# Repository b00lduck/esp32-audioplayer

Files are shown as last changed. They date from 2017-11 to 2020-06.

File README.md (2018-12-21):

# esp32-audioplayer
ESP32 based MP3 audio player with RFID control and case made from laser cutted plywood

!!! WORK IN PROGRESS !!!
!!! not functional yet !!!

## Used electronic hardware components:
* ESP32 NodeMCU module
* RFID-RC522 module (i.e. https://www.ebay.de/itm/172603664748)
* VS1053B module with SD-slot (i.e. http://www.ebay.de/itm/272761135002)
* Mifare classic 13.56MHz RFID cards (clones will do the job too, i.e. http://www.ebay.de/itm/122525501095)
* Adafruit PowerBoost 500 Charger module
* 3.7V LiPo battery 
* Class-D amplifier module
* SD-Card (i.e. 4GB)
* two Visaton FR7 (4 ohms) speakers
* Custom main board (see kicad folder for layout)
* Custom panel board (see kicad folder for layout)
* 1x 220uF 35V
* 1x 1uF 63V
* 4x 100nF 
* 2x 47nF
* 1x resistor ladder 4x 4.7k
* 1x 10R 
* 1x 10kR
* 1x 22kR
* 4x WSL10 (2x5 header 2.54mm with notch)
* 2x 2-pin header 2.54mm
* 4x 4-pin header 2.54mm
* some wire for airwires
* some insulated wire 1mm², red and black (for internal connections)
* 1x USB 2 Micro-B connector
* 1x power switch
* 1x USB 2 micro cable (for internal connection)
* optional: MEMS gyroscope module
* optional: 0.96 inch I2C OLED display

## Wood parts:
* 6 sheets, one for every side of the case
* 2 distance rings for the speakers

## Metal parts:
* 2x 100x75x0.8mm aluminium sheet

## 3D-Printed parts:
* 8x inner edge reinforcements
* 4x M3x3 standoff
* 8x M3*8 standoff (for main board)
* 4x M3x11 standoff (for MP3 board)
* 2x M3x6 standoff (for panel board)
* 2x M3x4 standoff (for panel board)
* 1x USB receptacle holder
* 1x SD-Card slot box
* 1x SD-Card slot cover

## Screws
* 4x M3x25 DIN 7991/ISO 10642 (countersunk allen bolt)
* 32x M3 DIN 934/ISO 4042 (nut)
* 8x M3 DIN 125/ISO 7089 (washer)
* 8x M3x20 DIN 912/ISO 4762 (cylinder head allen bolt)
* 2x M2x10 DIN 912/ISO 4762 (cylinder head allen bolt) for amp
* 2x M2 DIN 934/ISO 4042 (nut)
* 2x M2 DIN 125/ISO 7089 (washer)
* 8x M3x?? DIN 7991/ISO 10642 (countersunk allen bolt) for speakers
* 24x M3x15 DIN 7991/ISO 10642 (countersunk allen bolt) for inner corners

## Used software:
* VSCode with PlatformioIDE

## Used Arduino Libraries:
* SdFat 1.0.7
* MFRC522 1.3.6

## Port mapping
see src/config.h

## 3D printing
I used black 1.75 PETG filament for all parts.
Layer height was 0.15mm at a printign speed of 30mm/s.

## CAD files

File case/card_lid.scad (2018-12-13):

$fn  = 50;

width = 40;
height = 15;

// lid
lidThickness = 2.8;
pinLength = 4;
pinWidth = 5;
pinThickness = lidThickness / 2;
boxToLidSpacing = 1;
pinSpacing = 0.5;
lidReinforcementDepth = 2;

screwHoleHeadDiameter = 6;
screwHoleHeadDepth = 2;
screwHoleDiameter = 3.2;
screwHoleDistance = 6;

boxOverlap = 10;
boxThickness = 2;
boxDepth = 10;
boxKragen = 1.6;
boxFloorThickness = 3;

screwPoleDiameter = 8;

woodWidth = 4;

clipThickness = 0.6;
clipWidth = 4;
clipHeight = 5;
clipNoseHeight = 2;
clipNoseThickness = 1;
clipRadius = 1;

clipToWoodThruSpacing = 0.25;

lid();
//box();

module solidBox() {
    
    // kragen
    translate([0,0,-boxThickness/2]) cube([width + boxOverlap, height + boxOverlap, boxThickness], true);
 
    // durchführung
    translate([0, 0, (woodWidth)/2 - clipToWoodThruSpacing/2]) cube([width + boxThickness * 2, height + boxThickness * 2, woodWidth - clipToWoodThruSpacing], true);
 
    // rest
    translate([0, 0, (boxDepth-woodWidth-clipToWoodThruSpacing)/2 + woodWidth]) cube([width + (boxThickness - boxKragen) * 2, height + (boxThickness - boxKragen) * 2, boxDepth - woodWidth + clipToWoodThruSpacing], true);
    //snapClips();
}

module snapClips() {

    for(i = [-width/4,width/4])
    translate([i,0,0]) {
        translate([0, height/2 + boxThickness - boxKragen - clipThickness, woodWidth]) snapClip();
        rotate([180,180,0]) translate([0, height/2 + boxThickness - boxKragen - clipThickness, woodWidth]) snapClip();
    }

    translate([width/2 + boxThickness - boxKragen - clipThickness, 0, woodWidth]) rotate([0,0,-90]) snapClip();
    translate([-(width/2 + boxThickness - boxKragen - clipThickness), 0, woodWidth]) rotate([0,0,90]) snapClip();
}


module hollowBox() {      
   difference() { 
      solidBox();
             
      // oberer teil
      translate([-width/2,-height/2,-boxThickness]) cube([width, height, lidThickness]);    
      
      // unterer teil
      translate([0,0,boxDepth/2 - (boxFloorThickness-boxThickness)]) cube([width - boxKragen * 2, height - boxKragen * 2, boxDepth - boxThickness], true);    
       
       // pin slots
       pins();  
        
       // sd card slot
       translate([-4,0,boxDepth-boxFloorThickness/2]) cube([25,3,boxFloorThickness], true); 
   }   
   
}

module hollowBoxWithScrewPost() {
    difference() {
        hollowBox();
        translate([width/2-screwHoleDistance,0, lidThickness - boxThickness]) {
            cylinder(boxDepth-lidThickness, 2, 2);           
        }
    }

    translate([width/2-screwHoleDistance,0, lidThickness - boxThickness]) {
        difference() {
            screwPost();
            cylinder(boxDepth-lidThickness, 2, 2);           
        }    
   }
}

module box() {
    
    difference() {
        hollowBoxWithScrewPost();
        
        // M3 nut
        translate([width/2-screwHoleDistance,0,boxDepth]) 
        linear_extrude(height = 4, center = true) polygon([
            [3.17543,0],
            [1.58771,-2.75],
            [-1.58771,-2.75],
            [-3.17543,0],
            [-1.58771,2.75],
            [1.58771,2.75]
        ]);
        
        // notch for opening lid
        translate([width/2,-5,-3.4]) rotate([60,0,90]) cube([10,3.6,2]);      
    }    
}


module snapClip() {
       
    clipInnerRadius = clipRadius - clipThickness;
    
    translate([-clipWidth / 2, 0, 0]) {
    
        cube([clipWidth, clipThickness, clipHeight]);
        translate([0,clipRadius,clipHeight]) rotate([0,90,0]) 
        difference() {
            cylinder(clipWidth, clipRadius, clipRadius);
            cylinder(clipWidth, clipInnerRadius, clipInnerRadius);
            translate([0, -clipInnerRadius,0]) cube([clipInnerRadius * 3,clipInnerRadius * 2, clipWidth]);
        }
        translate([0,clipRadius*2 - clipThickness,0]) cube([clipWidth, clipThickness, clipHeight]);
        
        translate([clipWidth,clipRadius*2,0]) rotate([0,-90,0]) linear_extrude(height = clipWidth) polygon([
            [0, 0],
            [0, clipNoseThickness],
            [clipNoseHeight, 0]        
        ]);    
    }
}

module screwPost() {
    translate([0,0,lidReinforcementDepth]) cylinder(boxDepth-lidThickness-lidReinforcementDepth, screwPoleDiameter/2, screwPoleDiameter/2);
    translate([0,0,6.2]) cube([9,13,0], true);
}

module lidWithReinforcement() {
    translate([0,0,0]) {
        cube([width - boxToLidSpacing, height - boxToLidSpacing, lidThickness]);
        translate([screwHoleDistance, height/2, lidThickness]) cylinder(lidReinforcementDepth, screwPoleDiameter/2, screwPoleDiameter/2);
    }
}

module lid() {
    rotate([0,0,180]) translate([-width/2+boxToLidSpacing/2,-height/2+boxToLidSpacing/2,-boxThickness]) {
        difference() {
            lidWithReinforcement();
            translate([screwHoleDistance, height/2, 0]) cylinder(lidThickness + lidReinforcementDepth, screwHoleDiameter/2, screwHoleDiameter/2);
            translate([screwHoleDistance, height/2, 0]) cylinder(screwHoleHeadDepth, screwHoleHeadDiameter/2, screwHoleHeadDiameter/2);
       }
    }
    translate([0,0,0]) pins(pinSpacing);
 }
 
module pins(spacing = 0) {
    for(i = [-1,1]) 
        translate([(-pinLength-width)/2 , - pinWidth/2 + i*height/4, lidThickness/2 - boxThickness + spacing]) {
            cube([pinLength, pinWidth - spacing, pinThickness - spacing]);
        }
}

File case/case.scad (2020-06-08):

include <speakers.scad>;

$fn = 150;

width = 185;
depth = 110;
height = 110;

// 3.6 mm Pappel settings
//material = 3.6;
//kerf = 0.07;
//kerfExtraToothLen = 0.2;
//edgeHoleDistance = 11.6; // 11mm + ?
//edgeHoleRadius = 2

// 3 mm Plexi settings
material = 3;
kerf = 0.04;
kerfExtraToothLen = 0.2;
edgeHoleDistance = 11.8; // 11mm + ?
edgeHoleRadius = 1.6;

// 4 mm Birke settings
//material = 4;
//kerf = 0.07;
//kerfExtraToothLen = 0.2;



buttonDiameter = 24; 
//outerButtonDiameter = 34;
buttonSpread = 36;
buttonSpacing = 25;
buttonFoo = 0;

speakerHoleDistance = 60.5;
speakerDiameter = 70;
speakerSluts = 2.5;

fingersA = 9;
fingersB = 4;



//dimensions();

/*
    Material dimensions needed:
                                       
    1   top/bottom      240mm x 200mm   
    2   front/back      240mm x 200mm
    3   left/right      240mm x 120mm
    4   speaker ring    210mm x 110mm


    Cost for two cases without room for error:

    Rauchglas braun getoent     5mm     30€ (without rings)
    Rauchglas braun getoent     3mm     27€
    hellblau 5C18               3mm     30€
    Transparent                 5mm     21€ (without rings)
    Transparent                 3mm     21€
    Transparent kratzfest       3mm     29€
    grau 7C83                   3mm     31€ 
       
    https://www.plattenzuschnitt24.de/Acrylglas-Zuschnitt/Acrylglas-getoent/
    https://acrylglasplattenshop.de/acrylglas-getoent/       
    https://expresszuschnitt.de/3mm-PLEXIGLAS-hellgrau-GS-nach-Mass 
*/

color([1,0,0]) {
    //sheet1(); // front/bottom
    //sheet2(); // top/back
    sheet3(); // left/right
    //sheet4(); // speaker ring
    //kerftest();
}

module kerftest() {   
    sq = 40;    
    translate([0,-21,0]) {
        reducedSquare(sq, sq);
        fingersA(40, 40, 3, 0.5);
        fingersB(40, 40, 3, 0, true);
    }

    translate([0,21,0]) {
        reducedSquare(sq, sq);
        fingersA(40, 40, 3, 0);
        fingersB(40, 40, 3, 0);
    }
}

module dimensions() {
    difference() {
        square([211,111],true);
        square([210,110],true);
    }
}

module sheet1() {
    // front
    translate([60,0]) rotate([0,0,90]) faceA(width, depth);

    // bottom
    translate([-60,0,0]) rotate([0,0,90]) difference() {
        faceB(width, depth);
        translate([width/2 - 45.8,height/2 - 32,0]) circle(1.8);
        translate([-width/2 + 45.8,height/2 - 32,0]) circle(1.8);
        translate([width/2 - 45.8,height/2 - 98.8,0]) circle(1.8);
        translate([-width/2 + 45.8,height/2 - 98.8,0]) circle(1.8);
    }
}

module sheet2() {
    
    translate([-60,0,0]) rotate([0,0,90]) difference() {
        faceA(width, depth);
        translate([-10, 6]) sdCut();
        translate([55,14]) usbCut();
        translate([-65,17]) powerCut();
        translate([width/2 - 25.5, -height/2 + 27]) phoneCut();
        translate([width/2 - 26.5, -height/2 + 55]) ledsCut();
    }

    
    /*
    translate([60,0,0]) rotate([0,0,90]) difference() {
        faceB(width, depth);
        translate([-buttonSpread,-buttonSpacing+buttonFoo]) circle(buttonDiameter/2);
        translate([0,-buttonSpacing]) circle(buttonDiameter/2);
        translate([buttonSpread,-buttonSpacing+buttonFoo]) circle(buttonDiameter/2);
        rfid();
    }
    */
    
}

module rfid() {    
    distA = 34 / 2;
    distB = 25 / 2;   
    distC = 37 / 2;    
    translate([0,20,0]) {
        // two holes are enough and so the asymmetry of the board will be hidden
        translate([distC,distA,0]) circle(edgeHoleRadius);
        //translate([-distC,distB,0]) circle(edgeHoleRadius);
        //translate([distC, -distA,0]) circle(edgeHoleRadius);
        translate([-distC,-distB,0]) circle(edgeHoleRadius);
    }
}

module phoneCut() {
    circle(5.5);
}

module ledsCut() {
    translate([-5,0]) circle(2.1);
    translate([5,0]) circle(2.1);
}

module sdCut() {
    square([43.7 - kerf * 2, 18.7 - kerf * 2]);
}

module usbCut() {
    square([22 - kerf * 2, 11 - kerf * 2]);
}

module powerCut() {
    square([13,19], true);
}

module sheet3() {    
    translate([-60,0,0]) difference() {
        faceC(height, depth);
        rotate([0,0,90]) speakerCuts2(speakerHoleDistance, 4, speakerDiameter, 1.7);
    }
    translate([60,0,0]) difference() {
        faceC(height, depth);
        rotate([0,0,90]) speakerCuts2(speakerHoleDistance, 4, speakerDiameter, 1.7);
    }
}

module sheet4() {
    translate([-50,0,0]) {
        speakerRing(speakerHoleDistance, 4);
    }
    //translate([50,0,0]) {
    //    speakerRing(speakerHoleDistance, 4);
    //}
}

module faceA(a,b) {
    reducedSquare(a, b);
    fingersA(a, b, fingersA, 0);
    fingersB(a, b, fingersB, 0);
}

module faceB(a,b) {
    reducedSquare(a, b);
    fingersA(a, b, fingersA, 0.5);
    fingersB(a, b, fingersB, 0.5);
}

module faceC(a,b) {
    reducedSquare(a, b);
    fingersA(a, b, fingersB, 0.5);
    fingersB(a, b, fingersB, 0, true);        
}

// inner square of face without finger joints
module reducedSquare(a, b) {   
    reduction = (material - kerf) * 2;
    
    as = -(a-reduction)/2;
    bs = -(b-reduction)/2;
    
    at = -(a/2-material);
    bt = -(b/2-material);
    
    difference() {
        translate([as, bs]) square([a - reduction, b - reduction]);
        for(x = [-1,1]) for(y = [-1,1]) {
            translate([x * (at + edgeHoleDistance),y * (bt + edgeHoleDistance)]) circle(edgeHoleRadius);
        }
    }
}

// fingers on edge A of reduced square
module fingersA (a, b, num, offset) {    
    stride = a / (num + .5);
    for(x = [-1,1])
        for(i = [0+offset:num-offset]) {
            translate([stride/4 - a/2 + i * stride, x * (b/2 - material/2 + kerf)]) 
                square([stride/2 + kerf * 2, material + kerfExtraToothLen], true);
    }
}

// fingers on edge B of reduced square
module fingersB (a, b, num, offset, cut = false) {   
    stride = b / (num + .5);
    for(x = [-1,1]) {
        difference() {
            for(i = [0+offset:num-offset]) {
                translate([x * (a/2 - material/2 + kerf), stride/4 - b/2 + i * stride]) 
                    square([material + kerfExtraToothLen, stride/2 + kerf * 2], true);
            }
            if (cut) {
                translate([x * a/2, -(b/2 + kerf)]) square([material*2,material*2],true);    
                translate([x * a/2, (b/2 + kerf)]) square([material*2,material*2],true);    
            }
        }
    }
}

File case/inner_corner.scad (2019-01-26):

$fn = 60;
thickness = 3;
size = 16;

hole = 1.9;
reinf = 4.5;

nutThickness = 2.4;

dist = reinf;

rotate([0,90,0])
difference() { 
    foo();    
    translate([dist,dist,size-thickness]) bore();
    translate([dist,size-thickness,dist]) rotate([-90,0,0]) bore();
    translate([size-thickness,dist,dist]) rotate([0,90,0]) bore();
}

module foo() {    
    difference() {
        cube([size,size,size]);
        cube([size-thickness, size-thickness, size-thickness]);
        translate([size - thickness,0,0]) cube([thickness + 1,reinf,reinf]);
        rotate([90,0,90]) translate([size - thickness,0,0]) cube([thickness + 1,reinf,reinf]);
        rotate([-90,-90,0]) translate([size - thickness,0,0]) cube([thickness + 1,reinf,reinf]);
    }    
    boreReinforce();
}

module boreReinforce() {
    g = size - thickness - nutThickness;
    translate([dist, dist, g]) cylinder(thickness+nutThickness, reinf, reinf);
    translate([dist, g, dist]) rotate([-90,0,0]) cylinder(thickness + nutThickness, reinf, reinf);
    translate([g, dist, dist]) rotate([0,90,0]) cylinder(thickness + nutThickness, reinf, reinf);
}

module bore() {
    cylinder(thickness, hole, hole);
    translate([0, 0, -nutThickness-0.3])
    linear_extrude(height = nutThickness + 0.3) scale([1.01,1.01,1.01]) polygon([
        [3.17543,0],
        [1.58771,-2.75],
        [-1.58771,-2.75],
        [-3.17543,0],
        [-1.58771,2.75],
        [1.58771,2.75]
    ]);
}

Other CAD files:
case/speakers.scad
case/standoffs.scad
case/usb-B_port.scad
case/usb_port.scad

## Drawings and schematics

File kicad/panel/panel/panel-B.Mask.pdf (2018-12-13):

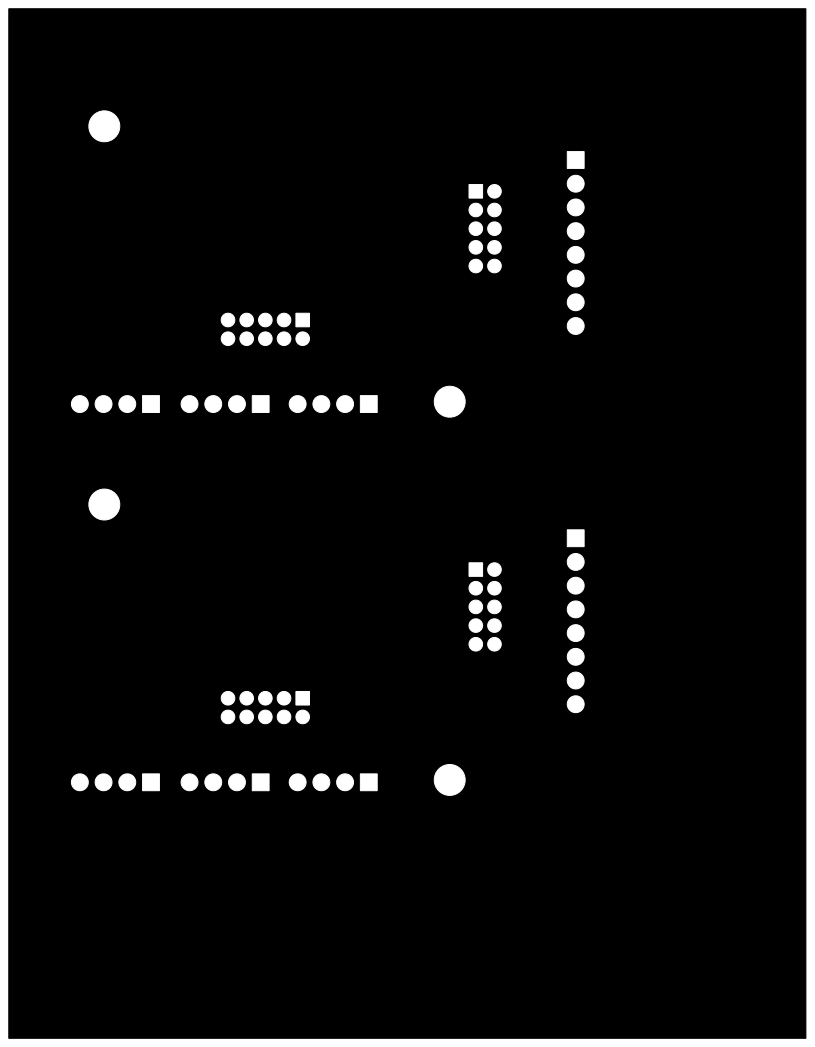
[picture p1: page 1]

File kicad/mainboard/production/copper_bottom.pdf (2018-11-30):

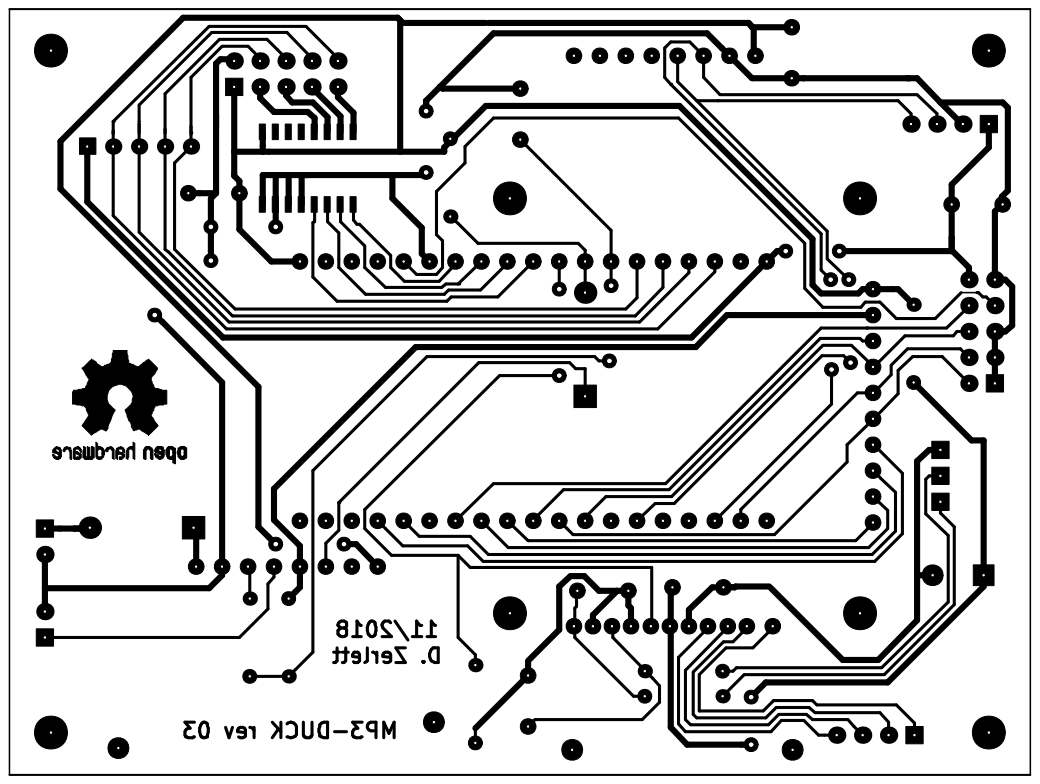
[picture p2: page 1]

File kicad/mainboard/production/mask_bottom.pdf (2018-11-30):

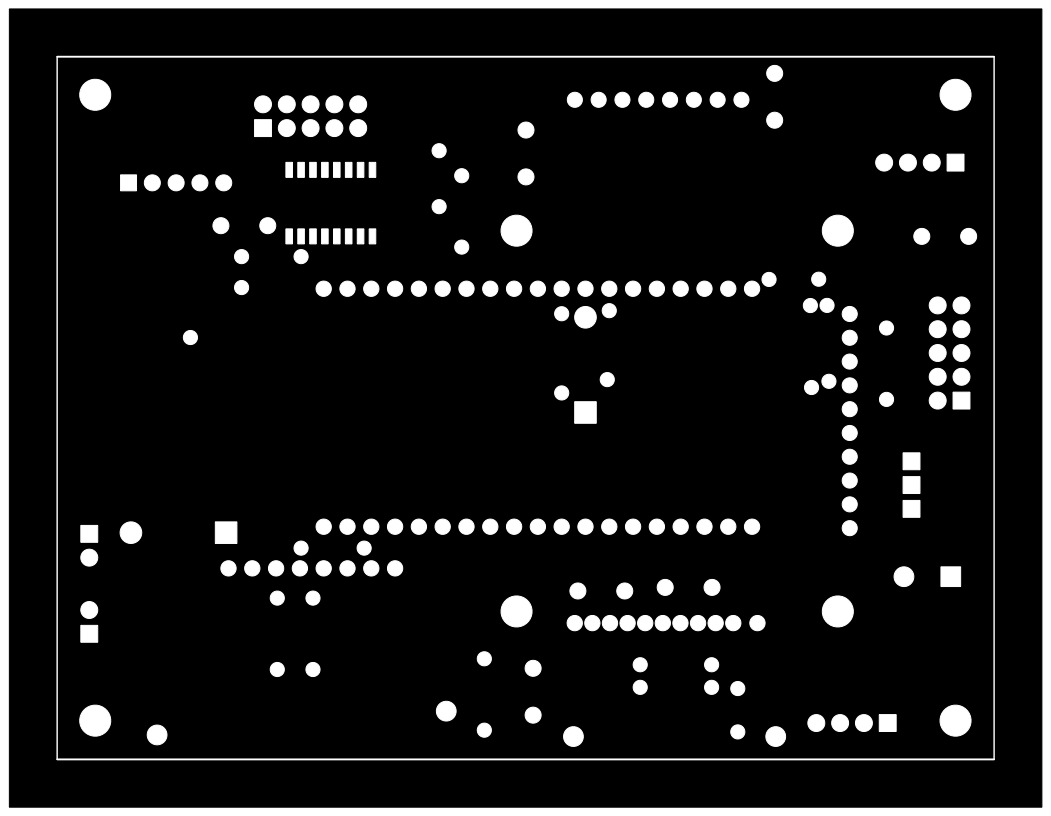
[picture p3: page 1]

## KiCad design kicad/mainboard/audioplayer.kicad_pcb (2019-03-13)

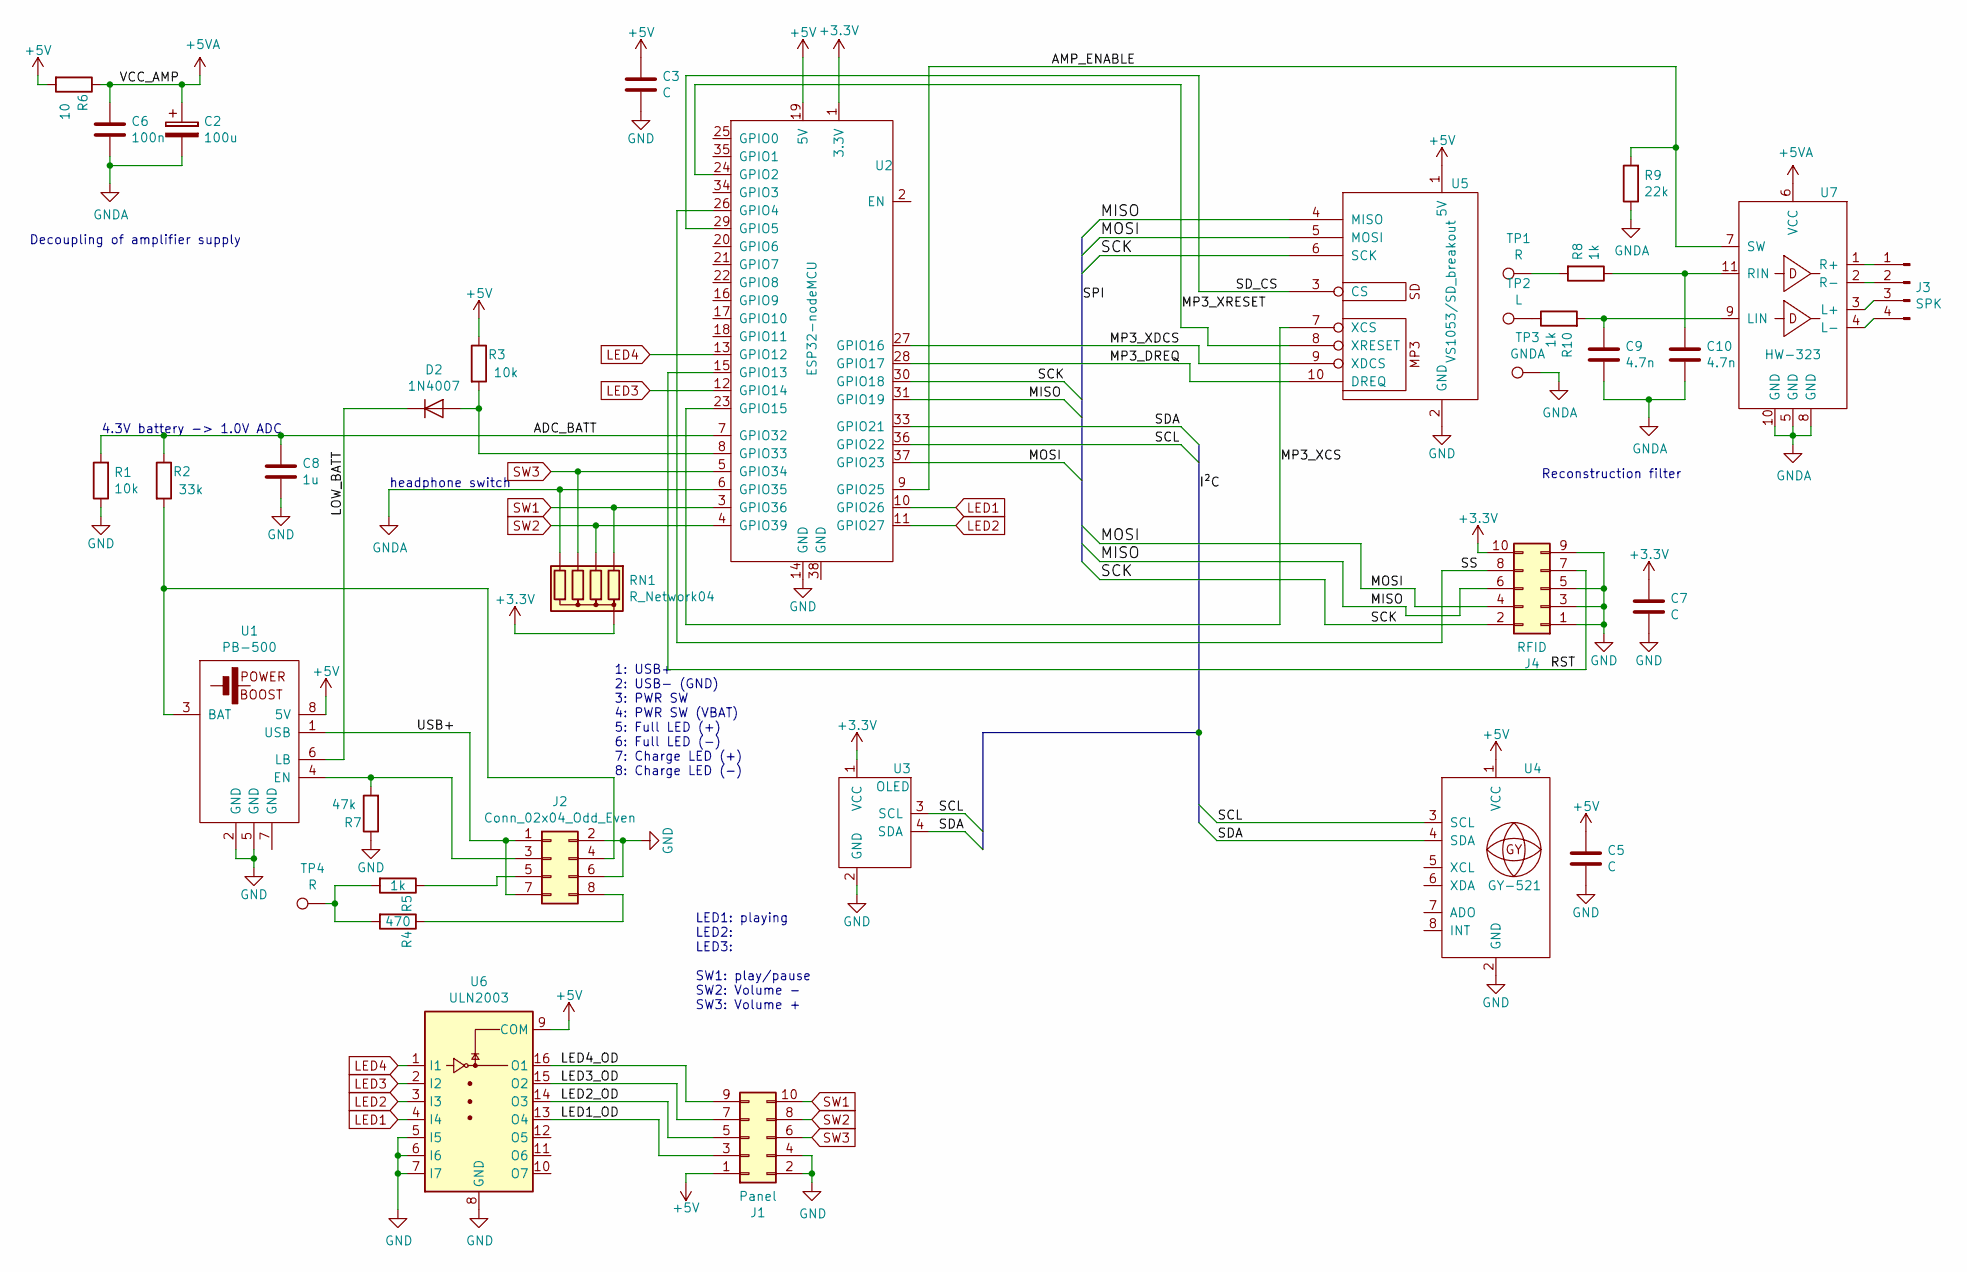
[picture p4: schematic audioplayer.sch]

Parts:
C2: 100u; CP_Radial_D10.0mm_P5.00mm
C3, C5, C7: C; C_Disc_D5.1mm_W3.2mm_P5.00mm
C6: 100n; C_Disc_D5.1mm_W3.2mm_P5.00mm
C8: 1u; C_Rect_L7.2mm_W5.5mm_P5.00mm_FKS2_FKP2_MKS2_MKP2
C9, C10: 4.7n; C_Rect_L7.0mm_W2.5mm_P5.00mm
D2: 1N4007; D_DO-41_SOD81_P10.16mm_Horizontal
J1: Panel; PinHeader_2x05_P2.54mm_Vertical
J2: Conn_02x04_Odd_Even; PinHeader_2x04_P2.54mm_Vertical
J3: SPK; PinHeader_1x04_P2.54mm_Vertical
J4: RFID; PinHeader_2x05_P2.54mm_Vertical
R1, R3: 10k; R_Axial_DIN0204_L3.6mm_D1.6mm_P7.62mm_Horizontal
R2: 33k; R_Axial_DIN0204_L3.6mm_D1.6mm_P7.62mm_Horizontal
R4: 470; R_Axial_DIN0204_L3.6mm_D1.6mm_P7.62mm_Horizontal
R5, R8, R10: 1k; R_Axial_DIN0204_L3.6mm_D1.6mm_P7.62mm_Horizontal
R6: 10; R_Axial_DIN0204_L3.6mm_D1.6mm_P7.62mm_Horizontal
R7: 47k; R_Axial_DIN0204_L3.6mm_D1.6mm_P7.62mm_Horizontal
R9: 22k; R_Axial_DIN0204_L3.6mm_D1.6mm_P7.62mm_Horizontal
RN1: R_Network04; R_Array_SIP5
TP1, TP4: R; PinHeader_1x01_P2.54mm_Vertical
TP2: L; PinHeader_1x01_P2.54mm_Vertical
TP3: GNDA; PinHeader_1x01_P2.54mm_Vertical
U1: PB-500; adafruit-pb500-charge
U2: ESP32-nodeMCU; esp32-nodemcu-noholes
U3: OLED; PinHeader_1x04_P2.54mm_Vertical
U4: GY-521; gy-521-noholes
U5: VS1053/SD_breakout; vs1053_breakout_upside_down
U6: ULN2003; SOIC-16W_5.3x10.2mm_P1.27mm
U7: HW-323; hw-323

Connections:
+3V3: C7.1, J4.10, RN1.1 (common), U2.1 (3.3V), U3.1 (VCC)
+5V: C3.1, C5.1, J1.1, R3.1, R6.2, U1.8 (5V), U2.19 (5V), U4.1 (VCC), U5.1 (5V), U6.9 (COM)
+5VA: C2.1, C6.1, R6.1, U7.6 (VCC)
/ADC_BATT: C8.1, R1.2, R2.1, U2.7 (GPIO32)
/AMP_ENABLE: R9.2, U2.9 (GPIO25), U7.7 (SW)
/LED1_OD: J1.3, U6.13 (O4)
/LED2_OD: J1.5, U6.14 (O3)
/LED3_OD: J1.7, U6.15 (O2)
/LED4_OD: J1.9, U6.16 (O1)
/LOW_BATT: D2.1 (K), U1.6 (LB)
/MISO: J4.6, U2.31 (GPIO19), U5.4 (MISO)
/MOSI: J4.4, U2.37 (GPIO23), U5.5 (MOSI)
/MP3_DREQ: U2.28 (GPIO17), U5.10 (DREQ)
/MP3_XCS: U2.23 (GPIO15), U5.7 (XCS)
/MP3_XDCS: U2.27 (GPIO16), U5.9 (XDCS)
/MP3_XRESET: U2.24 (GPIO2), U5.8 (XRESET)
/RST: J4.7, U2.15 (GPIO13)
/SCK: J4.2, U2.30 (GPIO18), U5.6 (SCK)
/SCL: U2.36 (GPIO22), U3.3 (SCL), U4.3 (SCL)
/SDA: U2.33 (GPIO21), U3.4 (SDA), U4.4 (SDA)
/SD_CS: U2.29 (GPIO5), U5.3 (CS)
/SS: J4.8, U2.26 (GPIO4)
/USB+: J2.1, J2.7, U1.1 (USB)
GND: C3.2, C5.2, C7.2, C8.2, J1.2, J1.4, J2.2, J2.6, J4.1, J4.3, J4.5, J4.9, R1.1, R7.1, U1.2 (GND), U1.5 (GND), U2.14 (GND), U3.2 (GND), U4.2 (GND), U5.2 (GND), U6.5 (I5), U6.6 (I6), U6.7 (I7), U6.8 (GND)
GNDA: C2.2, C6.2, C9.2, C10.2, R9.1, RN1.5 (R4), TP3.1, U2.6 (GPIO35), U7.5 (GND), U7.8 (GND), U7.10 (GND)
LED1: U2.10 (GPIO26), U6.4 (I4)
LED2: U2.11 (GPIO27), U6.3 (I3)
LED3: U2.12 (GPIO14), U6.2 (I2)
LED4: U2.13 (GPIO12), U6.1 (I1)
unnamed: C9.1, R10.2, U7.9 (LIN)
unnamed: C10.1, R8.1, U7.11 (RIN)
unnamed: D2.2 (A), R3.2, U2.8 (GPIO33)
unnamed: J2.3, R7.2, U1.4 (EN)
unnamed: J2.4, R2.2, U1.3 (BAT)
unnamed: J2.5, R5.1
unnamed: J2.8, R4.1
unnamed: J3.1, U7.1 (R+)
unnamed: J3.2, U7.2 (R-)
unnamed: J3.3, U7.3 (L+)
unnamed: J3.4, U7.4 (L-)
unnamed: R4.2, R5.2, TP4.1
unnamed: R8.2, TP1.1
unnamed: R10.1, TP2.1
SW1: J1.10, RN1.2 (R1), U2.3 (GPIO36)
SW2: J1.8, RN1.3 (R2), U2.4 (GPIO39)
SW3: J1.6, RN1.4 (R3), U2.5 (GPIO34)

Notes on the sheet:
1: USB+ 2: USB- (GND) 3: PWR SW 4: PWR SW (VBAT) 5: Full LED (+) 6: Full LED (-) 7: Charge LED (+) 8: Charge LED (-)
LED1: playing LED2: LED3: SW1: play/pause SW2: Volume - SW3: Volume +
4.3V battery -> 1.0V ADC
Reconstruction filter
Decoupling of amplifier supply
headphone switch

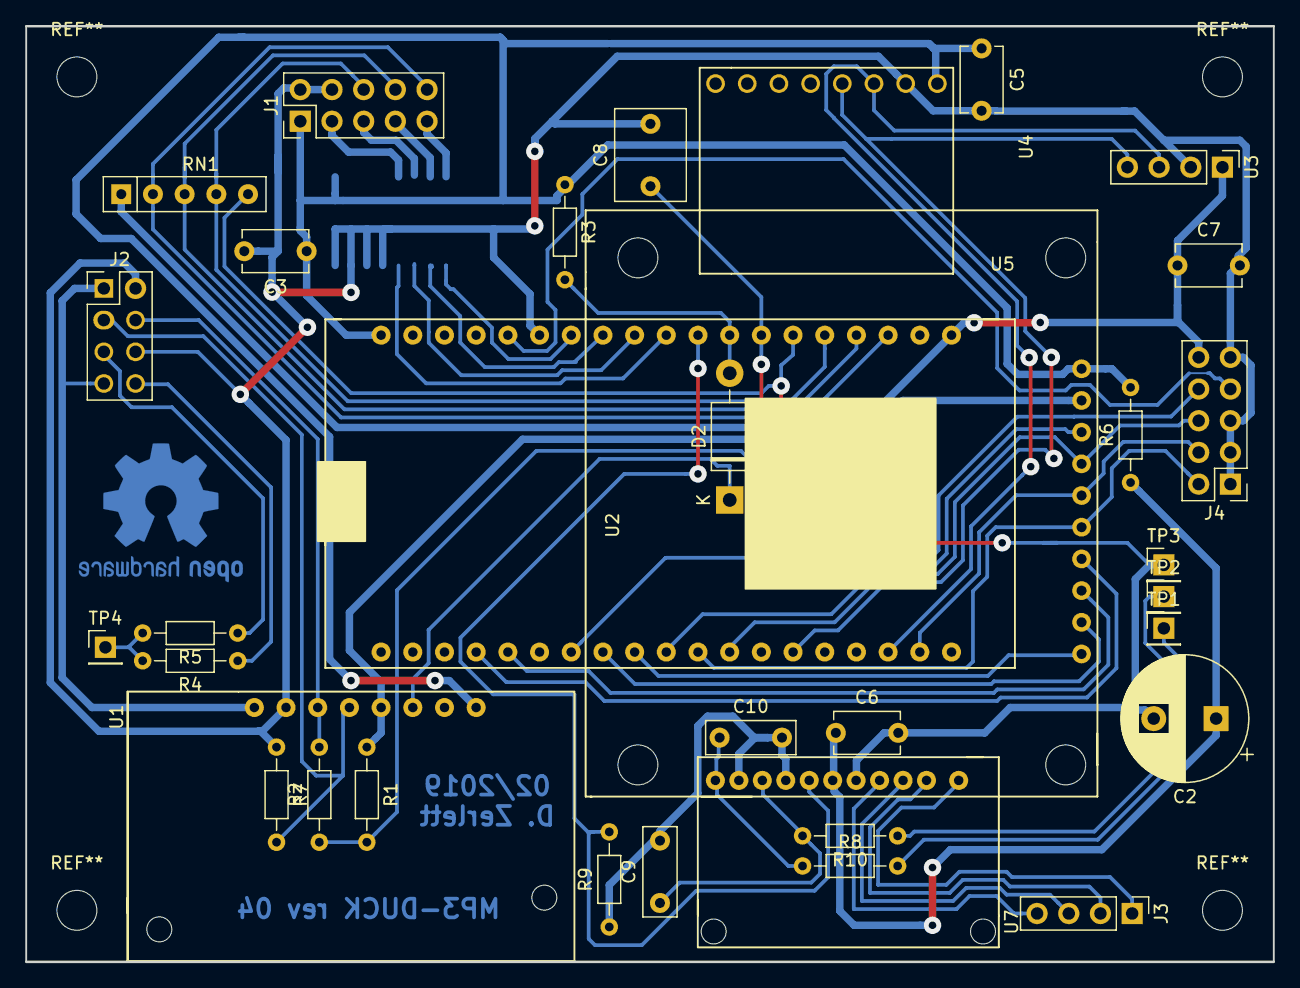
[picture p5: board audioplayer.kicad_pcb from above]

Board: 2 copper layers, 100.0 x 75.0 mm, 35 parts (1 on the bottom side), 46 nets.

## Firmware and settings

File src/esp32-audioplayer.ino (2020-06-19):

/**
 * 
 * Copyright 2018 D.Zerlett <daniel@zerlett.eu>
 * 
 * This file is part of esp32-audioplayer.
 * 
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
 */

#include <stdio.h>
#include <string.h>
#include <Wire.h>

#include "config.h"
#include "tools.h"
#include "buttons.h"
#include "VS1053.h"
#ifdef OLED
  #include "oled.h"
#endif
#include "rfid.h"
#include "sd.h"
#include "mapper.h"
#include "player.h"
#include "fatal.h"

VS1053          vs1053(VS1053_XCS_PIN, VS1053_XDCS_PIN, VS1053_DREQ_PIN, VS1053_XRESET_PIN);
RFID            rfid(MFRC522_CS_PIN, MFRC522_RST_PIN);
SDCard          sd(SD_CS_PIN);

#ifdef OLED
  Oled            oled(DISPLAY_ADDRESS);
  Fatal           fatal(oled);
  Player          player(fatal, oled, vs1053);
#else
  Fatal           fatal;
  Player          player(fatal, vs1053);
#endif

Mapper          mapper;
Buttons         buttons;

void setup() {

  Serial.begin(115200);                            
  Serial.println("\nStarting...");

  // Initialize GPIOs for LEDs
  // led1 green
  pinMode(LED1, OUTPUT);
  digitalWrite(LED1, LOW);
  
  // led2 white (player state)
  pinMode(LED2, OUTPUT);
  digitalWrite(LED2, LOW);
  
  // led3 red
//  pinMode(LED3, OUTPUT);
//  digitalWrite(LED3, LOW);

  // Initialize GPIOs for "amplifier enable"
  pinMode(AMP_ENABLE, OUTPUT);
  digitalWrite(AMP_ENABLE, LOW); 

  // Initialize buttons
  buttons.init();

  // Initialize GPIO for battery voltage
  pinMode(ADC_BATT, ANALOG);
  pinMode(LOW_BATT, INPUT);
  pinMode(SHUTDOWN, OUTPUT);
  digitalWrite(SHUTDOWN, LOW);

  Serial.println("GPIO init completed.");

  // Initialize I²C bus
  Wire.begin(I2C_SDA_PIN, I2C_SCL_PIN);
  #ifdef OLED
    oled.init();
    oled.loadingBar(0);  
  #endif  
  Wire.setClock(TWI_CLOCK);
  Serial.println("I²C init completed.");

  // Initialize SPI bus
  SPI.begin(SPI_SCK_PIN, SPI_MISO_PIN, SPI_MOSI_PIN);
  #ifdef OLED
    oled.loadingBar(25);
  #endif
  Serial.println("SPI init completed.");

  // Initialize RFID reader
  rfid.init();

  #ifdef OLED
    oled.loadingBar(50);
  #endif
  
  // Initialize SD card reader
  if (!sd.init()) {
      fatal.fatal("SD card error", "init failed");
  }

  Mapper::MapperError err = mapper.init(); 
  if (err != Mapper::MapperError::OK) {
    //player.play("/error.mp3");
    switch(err) {
      case Mapper::MapperError::MALFORMED_LINE_SYNTAX:
        fatal.fatal("Mapping error", "Syntax error");
      case Mapper::MapperError::MALFORMED_CARD_ID:
        fatal.fatal("Mapping error", "Illegal char in ID");
      case Mapper::MapperError::LINE_TOO_SHORT:
        fatal.fatal("Mapping error", "Line too short");    
      case Mapper::MapperError::LINE_TOO_LONG:
        fatal.fatal("Mapping error", "Line too long");
      case Mapper::MapperError::MAPPING_FILE_NOT_FOUND:
        fatal.fatal("Mapping error", "Mapping file not found");      
      case Mapper::MapperError::MALFORMED_FILE_NAME:
        fatal.fatal("Mapping error", "Malformed file name");   
      #ifdef FAIL_ON_FILE_NOT_FOUND      
        case Mapper::MapperError::REFERENCED_FILE_NOT_FOUND:
          fatal.fatal("Mapping error", "Referenced file not found");   
      #endif      
    }    
  }

  // initialize player
  player.init();

  player.play("/startup.mp3");

  oled.clear();  
}

uint16_t lpf = 0;


void loop() {

  bool changed = buttons.read();

  #ifdef OLED
  if (changed) {
    oled.buttons(buttons.state);
  }  
  #endif  

  // Cheapo one pole IIR low pass filter with unknown cutoff frequency (because sample rate is unknown).
  // This is good enough for battery monitoring though.
  //
  // lpf:
  // 0 is 0V battery voltage  
  // 1000 is approx. 4.12V battery voltage
  // in between linear (voltage divider)
  uint16_t batt = analogRead(ADC_BATT);
  uint16_t newLpf = (float)lpf * 0.95 + (float)batt * 0.05;
  lpf = newLpf;


  uint8_t lowBattFromPowerModule = digitalRead(LOW_BATT);
  if (lowBattFromPowerModule == 0) {
    pinMode(SHUTDOWN, OUTPUT);
    digitalWrite(SHUTDOWN, 1);
  }

  if (player.idleTime > 700000000) { // approx 15 min shutdown timer
    pinMode(SHUTDOWN, OUTPUT);
    digitalWrite(SHUTDOWN, 1);
  }
  
  // Volume Control
  if (buttons.buttonDown(0)) {
    player.increaseVolume();
  }

  if (buttons.buttonDown(2)) {
    player.decreaseVolume();
  }

  RFID::CardState cardState = rfid.checkCardState();
  
  switch(cardState) {
    case RFID::CardState::NEW_CARD:
      {
        char filename[MAX_FILENAME_STRING_LENGTH];
        Mapper::MapperError err = mapper.resolveIdToFilename(rfid.currentCard, filename);    
        switch(err) {
          case Mapper::MapperError::ID_NOT_FOUND:
            Serial.println(F("Card not found in mapping"));
            #ifdef OLED
              oled.trackName("Unknown card");
            #endif
            player.stop();        
          case Mapper::MapperError::LINE_TOO_LONG:
            fatal.fatal("Mapping error", "Long line/missing newline");         
          case Mapper::MapperError::MAPPING_FILE_NOT_FOUND:
            fatal.fatal("Mapping error", "Mapping file not found");         
          #ifdef FAIL_ON_FILE_NOT_FOUND  
            case Mapper::MapperError::REFERENCED_FILE_NOT_FOUND:
              fatal.fatal("Mapping error", "Data file not found"); 
          #endif              
          case OK:
            player.play(filename);
        } 
      }
      break;
    case RFID::CardState::REMOVED_CARD:
      Serial.println("removed card");
      player.stop();
      break;
    case RFID::CardState::FAULTY_CARD:
      Serial.println("faulty card");
      player.stop();
      break;
    case RFID::CardState::NO_CHANGE:
      break;
  }

  player.process();

}

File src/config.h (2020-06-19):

// Digital pins for LEDs
#define LED1                    26
#define LED2                    27
//#define LED3                    14
//#define LED4                    12

// Digital pin for power down
#define SHUTDOWN 12

// Digital pins for buttons
#define BUTTON1                 36
#define BUTTON2                 39
#define BUTTON3                 34
#define HEADPHONE_SWITCH        35

// Amplifier enable/disable (power saving)
#define AMP_ENABLE              25

// Battery monitoring
#define ADC_BATT                 32
#define LOW_BATT                 33

// Digital pins for VS1053 
#define VS1053_XCS_PIN          15
#define VS1053_XDCS_PIN         16
#define VS1053_DREQ_PIN         17
#define VS1053_XRESET_PIN       2 

// Digital pins for SD card
#define SD_CS_PIN               5

// Digital pins for MFRC522
#define MFRC522_CS_PIN          4
#define MFRC522_RST_PIN         13

#define SPI_SCK_PIN             18
#define SPI_MISO_PIN            19
#define SPI_MOSI_PIN            23

// Digital pins for I²C 
#define I2C_SDA_PIN             21
#define I2C_SCL_PIN             22

// Display I²C address
#define DISPLAY_ADDRESS         0x3c

// Number of bytes for the card ID
#define ID_BYTE_ARRAY_LENGTH    4

#define OLED
#define TWI_CLOCK 600000UL


//#define FAIL_ON_FILE_NOT_FOUND
#define FAST_BOOT
#define MAX_PLAYLIST_LENGTH 32
#define MAX_FILENAME_LENGTH 64

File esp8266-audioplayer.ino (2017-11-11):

/**
 * 
 * Copyright 2017 D.Zerlett <daniel@zerlett.eu>
 * 
 * This file is part of esp8266-audioplayer.
 * 
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
 */

#include <stdio.h>
#include <string.h>
#include <Wire.h>

#include "config.h"
#include "tools.h"
#include "VS1053.h"
#include "oled.h"
#include "rfid.h"
#include "sd.h"
#include "ringbuffer.h"
#include "mapper.h"

extern "C" {
  #include "user_interface.h"
}

void printDirectory();

enum playerState_t {PLAYING, STOPPED};

playerState_t   playerState;
File            dataFile;
CSMultiplexer   csMux(0x20);
RingBuffer      ringBuffer(20000);
VS1053          vs1053player(&csMux, VS1053_XCS_ADDRESS, VS1053_XDCS_ADDRESS, VS1053_DREQ, VS1053_XRESET_ADDRESS);
RFID            rfid(&csMux, MFRC522_CS_ADDRESS, MFRC522_RST_ADDRESS);
SDCard          sd(&csMux, SD_CS_ADDRESS);
Oled            oled(0x3c);
Mapper          mapper;

void fatal(char* title, char* message) {
  Serial.println(F("FATAL ERROR OCCURED"));
  Serial.println(title);
  Serial.println(message);
  oled.fatalErrorMessage(title, message);
}

void setup() {

  Serial.begin(115200);                            
  Serial.println("\nStarting...");
  system_update_cpu_freq(160);

  // Initialize I²C bus
  Wire.begin(2, 4);
  csMux.init();
  oled.init();
  oled.loadingBar(0);  
  Wire.setClock(600000L);

  // Initialize SPI bus
  SPI.begin();
  oled.loadingBar(25);

  // Initialize SD card reader
  if (!sd.init()) {
      fatal("SD card error", "init failed");
  }

  oled.loadingBar(50);

  // Initialize RFID reader
  rfid.init();
  
  oled.loadingBar(75);        

  Mapper::MapperError err = mapper.init(); 
  switch(err) {
    case Mapper::MapperError::MALFORMED_LINE_SYNTAX:
      fatal("Mapping error", "Syntax error");
    case Mapper::MapperError::MALFORMED_CARD_ID:
      fatal("Mapping error", "Illegal char in ID");
    case Mapper::MapperError::LINE_TOO_SHORT:
      fatal("Mapping error", "Line too short");    
    case Mapper::MapperError::LINE_TOO_LONG:
      fatal("Mapping error", "Line too long");
    case Mapper::MapperError::MAPPING_FILE_NOT_FOUND:
      fatal("Mapping error", "Mapping file not found");      
  }

  // Initialize audio decoder
  vs1053player.begin();
  vs1053player.printDetails();
  
  playerState = STOPPED;

  oled.loadingBar(100);
  
  oled.clear();
}

void play_request(byte cardId[ID_BYTE_ARRAY_LENGTH]) {
  
  char filename[MAX_FILENAME_STRING_LENGTH];
  Mapper::MapperError err = mapper.resolveIdToFilename(cardId, filename);    
  switch(err) {
    case Mapper::MapperError::ID_NOT_FOUND:
      Serial.println(F("Card not found in mapping"));
      oled.trackName("Unknown card");
      stop_request();        
      return;
    case Mapper::MapperError::LINE_TOO_LONG:
      fatal("Mapping error", "Long line/missing newline");         
      break;
    case Mapper::MapperError::MAPPING_FILE_NOT_FOUND:
      fatal("Mapping error", "Mapping file not found");         
      break;
    case Mapper::MapperError::REFERENCED_FILE_NOT_FOUND:
      fatal("Mapping error", "Data file not found"); 
      break;    
  } 
  
  dataFile.open(filename, FILE_READ);   
  if (!dataFile) {
    fatal("Error", "Unknown IO problem");
  }
  oled.trackName(filename);

  // skip ID3v2 tag if present
  char header[10];
  uint16_t n = dataFile.read(header, 10);
  if ((header[0] == 'I') && (header[1] == 'D') && (header[2] == '3')) {    
    uint32_t header_size = header[9] + ((uint16_t)header[8] << 7) + ((uint32_t)header[7] << 14) + ((uint32_t)header[6] << 21);
    Serial.printf(F("Found ID3v2 tag at beginning, skipping %d bytes\n"), header_size);
    dataFile.seekSet(header_size);    
  } else {
    dataFile.seekSet(0);
  }
    
  playerState = PLAYING;
  vs1053player.setVolume(80);                 
}

void stop_request() {
  dataFile.close();
  vs1053player.processByte(0, true);
  vs1053player.setVolume(0);                  
  vs1053player.stopSong();                       
  ringBuffer.empty();                            
  playerState = STOPPED; 
}

void loop() {

  RFID::CardState cardState = rfid.checkCardState();
  
  switch(cardState) {
    case RFID::CardState::NEW_CARD:
      play_request(rfid.currentCard);
      break;
    case RFID::CardState::REMOVED_CARD:
      stop_request();
      break;
    case RFID::CardState::FAULTY_CARD:
      stop_request();
      break;
    case RFID::CardState::NO_CHANGE:
      break;
  }

  uint32_t maxfilechunk;
    
  switch (playerState) {

    case PLAYING:      
      // fill ring buffer with MP3 data
      maxfilechunk = dataFile.available();
      if (maxfilechunk > 1024) {
        maxfilechunk = 1024;      
      }
      while (ringBuffer.space() && maxfilechunk--) {
        ringBuffer.put(dataFile.read());
      } 
      
      // Try to keep VS1053 filled
      while (vs1053player.data_request() && ringBuffer.avail()) { 
        vs1053player.processByte(ringBuffer.get(), false);
      }

      // stop if data ends
      if ((dataFile.available() == 0) && (ringBuffer.avail() == 0)) {      
        stop_request();
      }
      break;

    case STOPPED:
      oled.trackName("");
      break;    
    
  }

}

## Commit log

2017-08-10 license changed to GPLv3 use multiplexer for SPI CS lines
2017-09-11 added schematics
    [audioplayer.kicad_pcb, audioplayer.sch]
2018-10-10 migrated to PlatformIO and ESP32
    [audioplayer-2018-10-04-17-41-54.sch, audioplayer.sch]
2018-10-12 buttons and leds
    [audioplayer.sch]
2018-11-03 schematic improvements
    [audioplayer.sch]
2018-11-05 case cut files
    [case.scad, sheet1.dxf, sheet2.dxf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]
2018-11-05 kerf test pattern
    [case.scad]
2018-11-05 speaker ring
    [case.scad, speakerRing.dxf, speakers.scad]
2018-11-06 card lid
    [card_lid.scad, card_lid.stl, card_lid_box.stl]
2018-11-06 better card lid
    [card_lid.scad, card_lid.stl, card_lid_box.stl]
2018-11-08 SD card slot improvements
    [audioplayer.sch, card_lid.scad, card_lid.stl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]
2018-11-08 case improvements
    [backside.dxf, card_lid.scad, card_lid.stl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]
2018-11-08 changed ring
    [speakers.scad]
2018-11-08 changed backside holes
    [backside.dxf, case.scad]
2018-11-13 first board revision completed
    [audioplayer.sch]
2018-11-13 ADC code for battery monitoring, change GPIOs according to board
2018-11-14 fix board
    [audioplayer.kicad_pcb]
2018-11-15 board improvements
    [audioplayer.kicad_pcb, audioplayer.sch]
2018-11-23 board rev 02
    [audioplayer.kicad_pcb, audioplayer.sch]
2018-11-30 board revision 03
    better ground handling, vastly reduced background noise
    added reconstruction filter to vs1053 output
    added possibillity to add headphone jack
    use smd darlington array
    add diode for battery low signal
    add diode for charging connector (reverse polarity protection just in case)
    use 10-pin panel connector and swapped connections for better PCB routing
    swapped some GPIO-Pins for better PCB routing (i.e. RFID SS,SCK)
    use restor ladder for button GPIOs
    removed supply decoupling for SD/MP3 board
    [audioplayer.kicad_pcb, audioplayer.sch]
2018-12-02 3mm plexi case test
    [backside.dxf, case.scad, sheet1.dxf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]
2018-12-02 kicad autosave
2018-12-02 fix kerf calculation
    [case.scad]
2018-12-05 Case changes: holes for inner corner reinforecemnts holes for RFID reader moved USB jack and power switch
    [case.scad, inner_corner.scad, inner_corner.stl]
2018-12-06 add 3.6mm pappel dxf
    [3.6mm-pappel-bottom.dxf, 3.6mm-pappel-front.dxf, 3.6mm-pappel-sheet2.dxf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]
2018-12-07 3.6mm pappel fixes moved kicad software refactoring/preparations for wifi
    [3.6mm-pappel-bottom.dxf, 3.6mm-pappel-front.dxf, 3.6mm-pappel-sheet1.dxf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]
2018-12-13 case fixes
    [CFFFP_card_lid.3mf, card_lid.scad, case.scad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]
2018-12-13 add panel board
    [panel.kicad_pcb, panel.sch]
2018-12-13 changed sd cut
    [case.scad]
2018-12-19 flipped holes for panel board
    [case.scad]
2018-12-19 standoffs for panel
    [standoffs.scad]
2018-12-21 fix refactored software for new hardware
    [config.h, esp32-audioplayer.ino, oled.cpp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]
2019-01-26 case changes
    [case.scad]
2019-01-26 change nut spacing!
    [case.scad, inner_corner.scad]
2019-02-17 board rev04
    [audioplayer.kicad_pcb, audioplayer.sch]
2019-03-13 case changed et al
    [audioplayer.kicad_pcb, audioplayer.sch, case.scad]
2019-11-18 playlist support for folders
    [3.6mm-pappel-sheet1.dxf, 3.6mm-pappel-sheet2.dxf, 3.6mm-pappel-sheet3.dxf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]
2020-06-08 change speaker grids
    [case.scad, speakers.scad]
2020-06-08 usb b port
    [usb-B_port.scad]
2020-06-08 kerf change
    [case.scad]
2020-06-19 add power management dropi-in board
    [power.kicad_pcb, power.sch]
2020-07-19 fix usb port size in case
    [usb-B_port.scad]

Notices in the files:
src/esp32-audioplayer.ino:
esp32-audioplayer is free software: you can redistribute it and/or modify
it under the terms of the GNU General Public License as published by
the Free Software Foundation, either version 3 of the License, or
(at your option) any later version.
